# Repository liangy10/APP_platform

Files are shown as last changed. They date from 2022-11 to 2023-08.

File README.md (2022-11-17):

# APP_platform

We designed a low-cost glass pipette pulling device called affordable pipette puller (APP) using Tinkercad and manuscript will be submitted for review soon.
This is what it looks as a whole.

APP_whole

For 3D printable parts, we have attached stl files (from A through E) exported from Tinkercad as well as the gcode files sliced by Ultimaker Cura for printing using Creality Ender 3 v2. 

Parts

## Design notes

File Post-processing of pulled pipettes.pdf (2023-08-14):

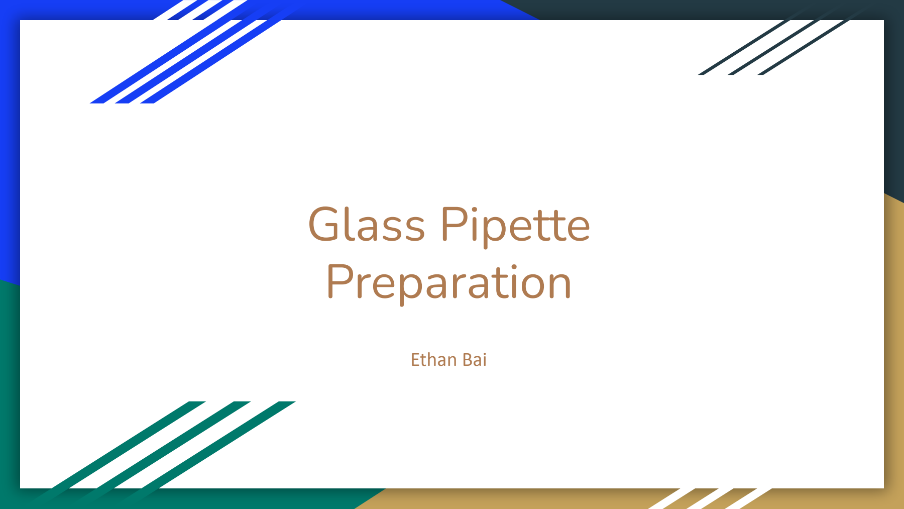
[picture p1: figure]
Glass Pipette Preparation; Ethan Bai

# Introduction

Many methods of injecting therapeutics to the brain, such as

- Intracerebral injections

Has its upsides, such as its precise targeting, however one major negative is the its invasive nature

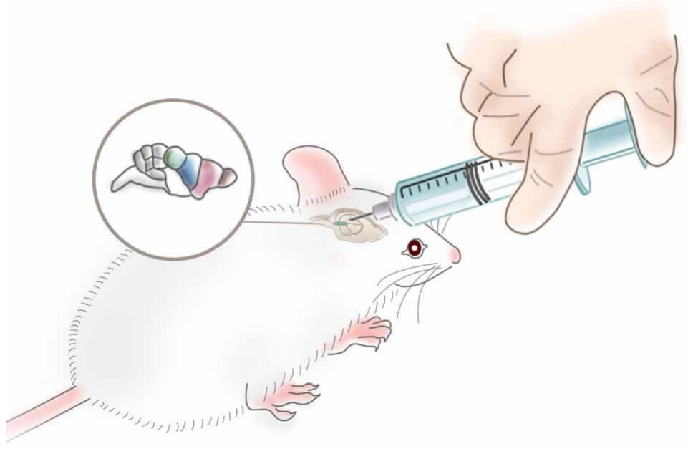
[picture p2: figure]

# Motivations

Thin tipped tools

- Thin-tip glass pipette

Problems

- Affordability
- Price of obtaining glass pipettes
- Requires conversion of professional programmable pipette pullers (thousands of dollars)
- Accessibility
- Non electrophysiological labs lack access to pipette pullers

3D Printing can drastically reduce the price

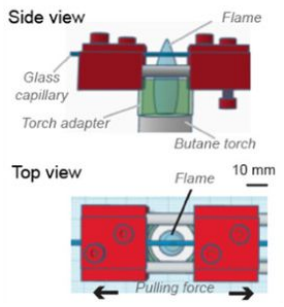
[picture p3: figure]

https://onlinelibrary.wiley.com/doi/full/10.1002/nep3.20

Pulling Device

# My Project: Processing and Calibrating Glass Pipettes

- Calibrating
- Trimming
- Beveling

# Calibrating

- Different therapeutics to be injected are different sizes, so we must cater our pipettes to these needs
- Liquid delivery - 20 μm
- Cell delivery - 40-50 μm
- Determining where to cut pipette
- Visible measuring scale in the microscope lens
■ Reticle
- Allows measurement of items visible in the microscope

Reticle

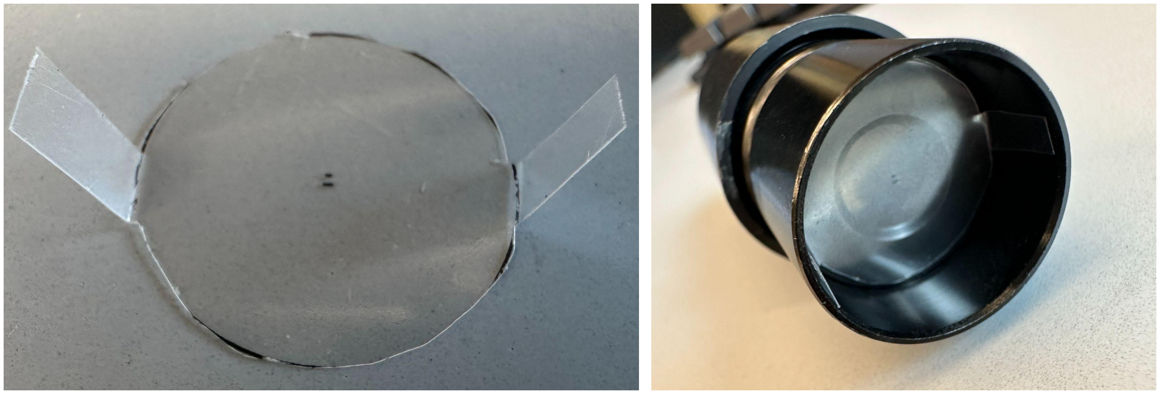
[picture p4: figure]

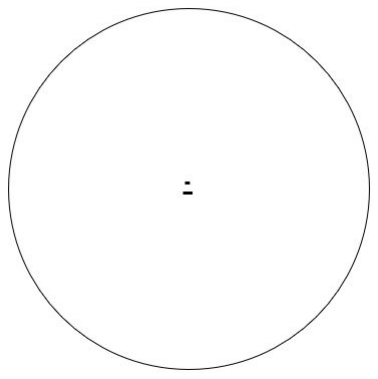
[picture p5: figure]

# Reticle

Microsoft Word used to create the reticle

1. Measure the diameter of the microscope lens
2. Create a circle of that diameter in word
- Set height and width equal to the diameter
3. Convert desired length in microscope to actual length on the reticle
- For 100x magnification, 20 μm * 100 = 2 mm
- 40 μm * 100 = 4 mm
4. Create line of that length and center it in the circle with align tool
- Multiple lines -> group first
5. Print out reticle on a clear film
6. Cut out the reticle
- Cut out “ears” on the reticle so it's easy to take out of the microscope

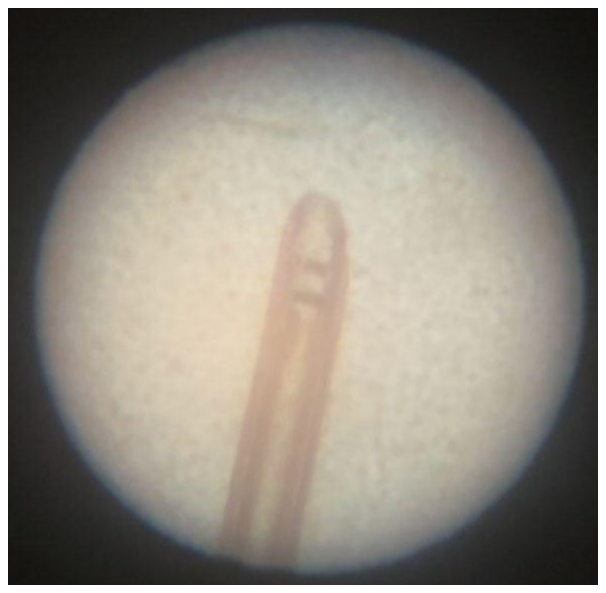
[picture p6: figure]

# Problem with Old Reticle

Problem:

- Intended lengths obtained from calculations were off
- Ex: The line for 20 μm was actually 150 μm through the microscope
- Hidden lens within the microscope

Solution:

1. Calculate magnification factor
- Ex: 150/20 =7.5
2. Divide length of the line on the reticle by magnification
- 2 mm/7.5 = 0.2667 mm

# Trimming

Shining a bright light through one of the lenses projects a bright dot

Trimming Procedure:

1. Match the line on the reticle with the pipette to measure desired diameter
2. Turn off the microscope light and turn on the flashlight
3. Make a cut on the pipette where the bright dot is

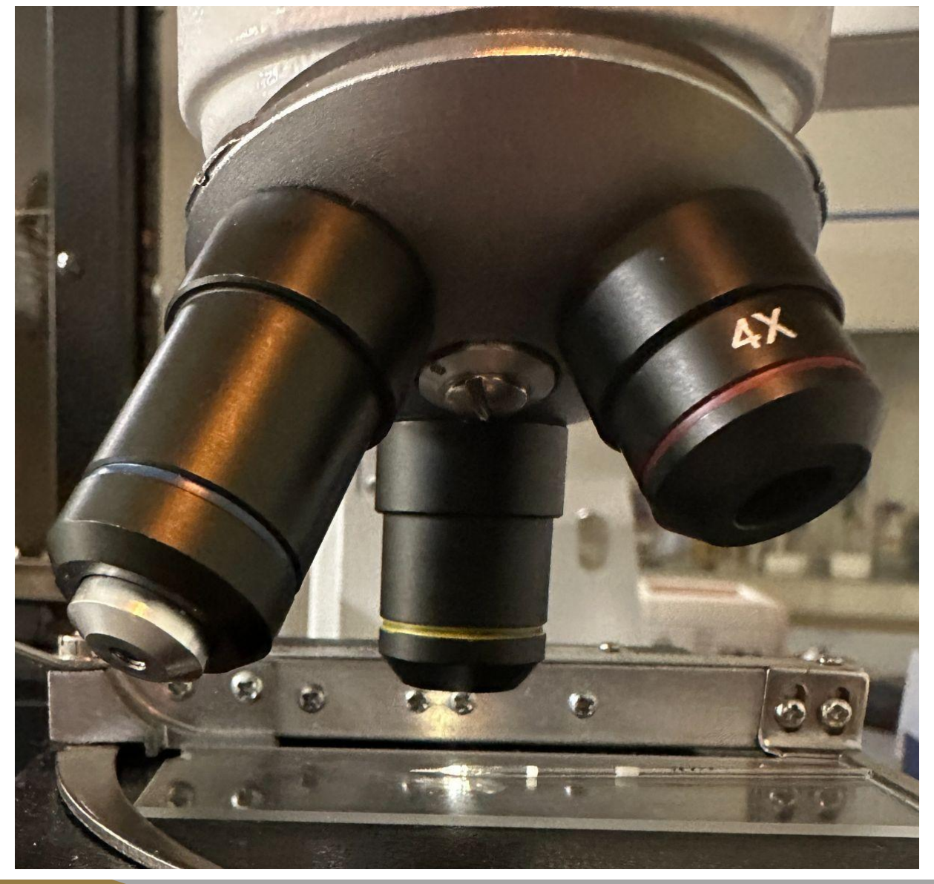
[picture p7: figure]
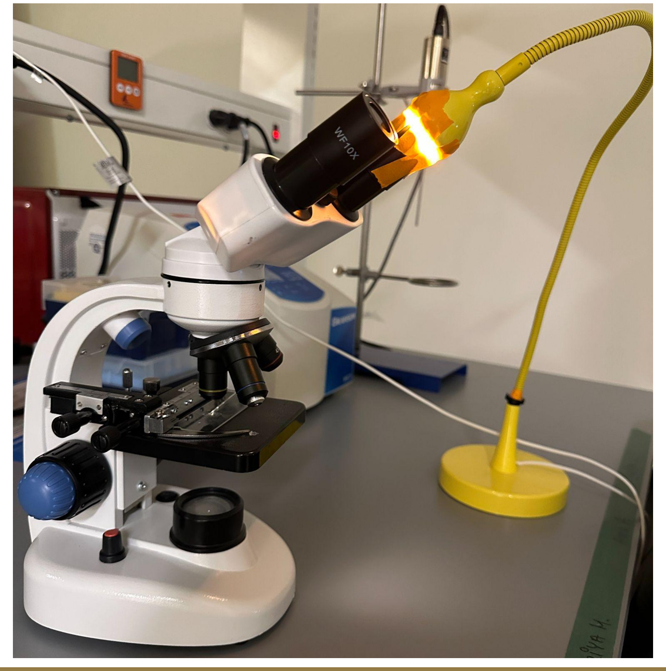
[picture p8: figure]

# Beveling

We can bevel the pipettes with a spinning hard drive disk

Put the tip on the surface of the disk very carefully at a small angle

- Too much force could break the tip
- Too large of an angle could result in a dull tip

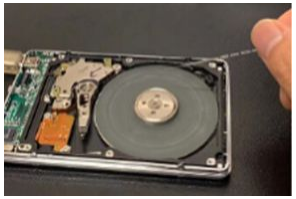
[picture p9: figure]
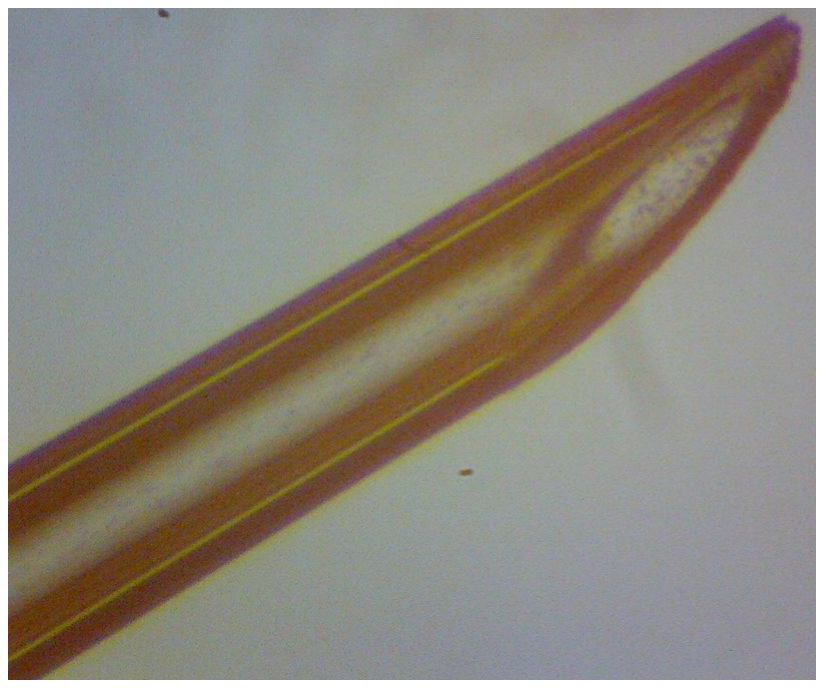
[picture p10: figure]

# Software

We can confirm if our measurements were correct using an app called imageJ.

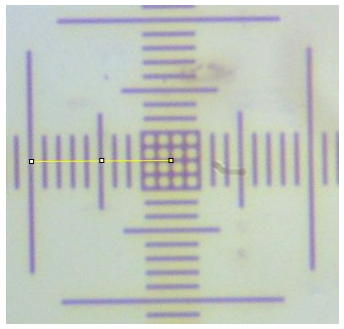
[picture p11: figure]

1. Take screenshot of the grid on the slide
- Each space is 10 μm
2. Draw a line from origin to any line on the scale
3. Calculate that distance in μm
4. Analyze -> Set Scale
- Change known distance to calculated length
- Change units to um
- Check global

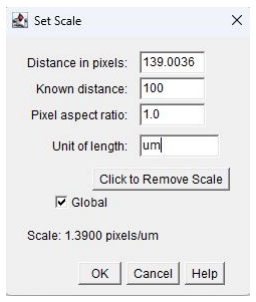
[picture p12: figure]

# Thank You

# Questions?

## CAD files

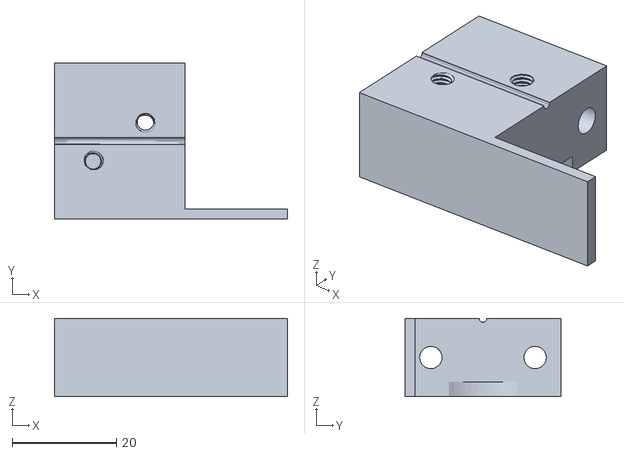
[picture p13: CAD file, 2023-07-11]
A.stl
44.7 x 30.0 x 15.0

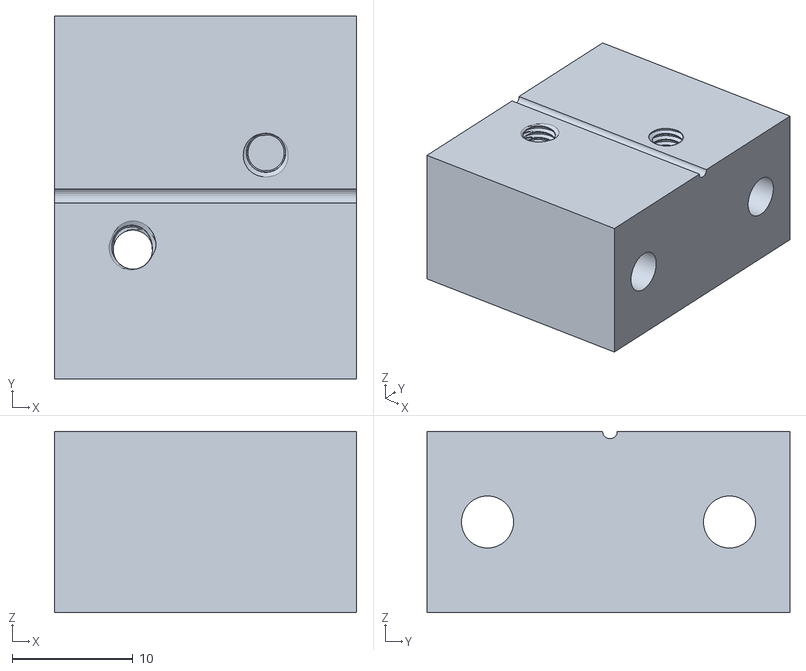
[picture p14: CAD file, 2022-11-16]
B.stl
25.0 x 30.0 x 15.0

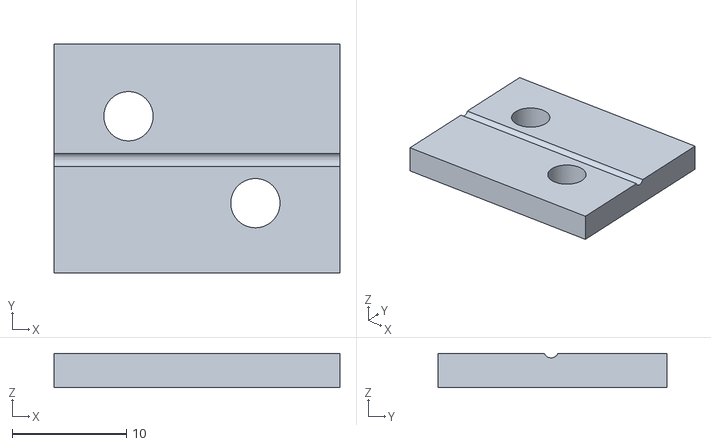
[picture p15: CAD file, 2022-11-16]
C.stl
25.0 x 20.0 x 3.00

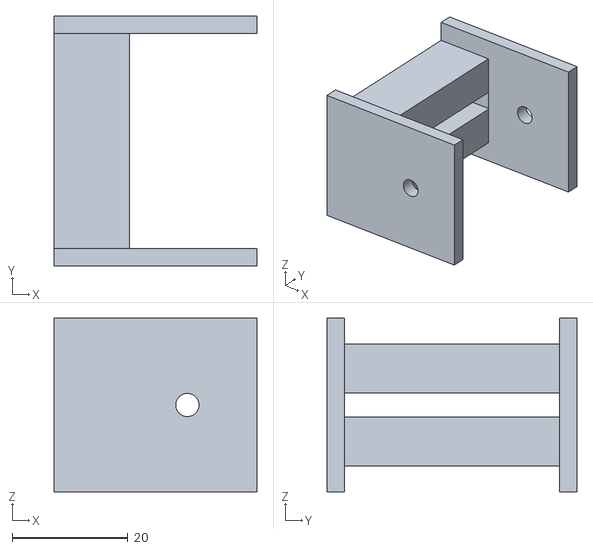
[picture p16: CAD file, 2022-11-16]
E.stl
35.0 x 43.1 x 30.0

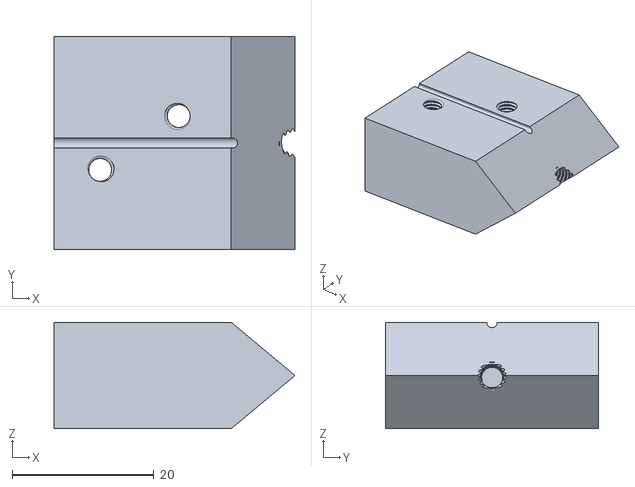
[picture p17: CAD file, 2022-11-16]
D.stl
34.0 x 30.0 x 15.0

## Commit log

2023-07-11 Delete A.stl
    incorrect file. updated A.stl uploaded in its place
    [A.stl]
2023-07-11 Add files via upload
    updated version of A.stl
    [A.stl]
